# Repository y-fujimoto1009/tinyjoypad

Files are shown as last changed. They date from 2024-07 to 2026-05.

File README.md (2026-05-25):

# tinyjoypad キット

tinyjoypad キットは、attiny85を使ったゲーム機を作成するためのキットです。<br>
tinyjoypadプロジェクトは
[こちら](https://www.tinyjoypad.com/tinyjoypad_attiny85) 



## 内容物


- 基板 x 1
- LED x 1
- ピンヘッダー（2×3） x 1
- スライドスイッチ x 1
- attiny85 x 1
- 丸ピンICソケット (8P) x 1
- 抵抗（10kΩ） x 2
- 抵抗（22kΩ） x 2
- 抵抗（33kΩ） x 2
- 抵抗（91kΩ） x 2
- タクトスイッチ x 5
- スイッチキャップ x 5
- ブザー x 1
- ボタン電池ホルダー x 1
- 0.96インチ有機ELディスプレイ(OLED)  x 1
- USBasp AVRライタ x 1(スイッチサイエンスで購入した方のみ）

## 自分で用意する必要があるもの
最近は100均などでも手に入りますね。
- はんだごて、はんだ
- マスキングテープ
- ニッパー
- ボタン電池（CR2032）

## 作成手順
1. 抵抗を基板に書かれた場所に配置します。間違えないようにしましょう。向きは関係ありません。<br>
はんだで接続できたら、余った足はニッパーでカットしてOKです。
どの抵抗かわからなくなっても落ち着いてカラーコードを確認すれば大丈夫です。<br>

<br>
 10kΩ：茶赤黒黒茶<br><br>
 
 22kΩ：赤赤黒赤茶<br><br>
 
 33kΩ：橙橙黒赤茶<br><br>
 
 91kΩ：茶赤黒茶白<br>

 

2. OLEDを取り付けます。斜めにならないようにマスキングテープなどで固定してからはんだ付けしましょう。<br><br>


3. 電源スイッチを下に向けて取り付けます。ぐらぐらしますので、マスキングテープなどで仮固定してからはんだ付けしましょう。<br><br>


4. タクトスイッチを取り付けます。向きは関係ありません。スイッチキャップも付けましょう。あまり強く押さなくても取り付けられます。<br><br>


5. LEDを取り付けます。足の短い方（カノード）をGNDの方にして取り付けてください。余った足はニッパーでカットしてOKです。<br><br>
IMG_1461 (1)

6. ピンヘッダ、ICソケットを取り付けます。ICソケットにはattiny85を取り付けます。attiny85は左側にくぼみがくるように取り付けてください。<br><br>
IMG_1463 (1)

7. ブザーも向きがあります。＋と書いてる方を間違えずに取り付けてください。これで表面は完成です。<br><br>
IMG_1464 (3)

8. 裏を向けてボタン電池ホルダーを取り付けます。今までと違い表面実装部品なので、先に基板にはんだを少し盛ってから、上から温めて接続するとうまくいきます。<br><br>



あとは電池を＋面が表になるように接続して電源をONにすればゲームが起動するはずです！おめでとう！
起動しない場合ははんだのミス（隣と接続されてしまっている箇所が無いかなど）、attiny85の向き、取付忘れなどないか確認してください。
お問い合わせはk.u.i.f1009@gmail.comまで

## プログラムのインストール手順
初期状態でスペースインベーダーをインストールしていますが、tinyjoypadプロジェクトでは他にも面白いゲームが公開されています。
現状(2024年7月時点）でうまくいったインストール手順を紹介します。

1. [Zadig](https://zadig.akeo.ie/)にアクセスして、Zadigソフトをインストールします。
2. キットについているUSBaspをPCと接続します。
3. Zadigを起動し、USBaspを選択してlibusbkを選択してインストールします。
4. [ArduinoIDE](https://www.arduino.cc/en/software)をインストールします。
5. 基本設定ー＞追加のボードマネージャのURLに次のURLを追加します。https://descartes.net/package_drazzy.com_index.json
6. ツールー＞ボードー＞ボードマネージャの検索欄にattinyと入力してATTinyCore by Spence Kondeのバージョン1.3.2を選択してインストールします。
8. [SSD1306ライブラリ](https://github.com/Defragster/ssd1306xled)をダウンロードし、スケッチー＞ライブラリをインクルードー＞.ZIP形式のライブラリをインストールへと進み、ダウンロードしたzipファイルを選択してインストールを行います。
9. [ゲームデータ](https://github.com/cheungbx/gametiny)をダウンロード、解凍し、好きなゲームの.inoファイルを起動します。
10. ツールー＞ボードー＞ATTinyCoreー＞Attiny25/45/85を選択します。
11. チップはATtiny85、クロックは8MHz(internal)、そして書込装置はUSBaspを選択します。
12. スケッチー＞書き込み装置を使って書き込むを選択します。
13. プログラムが書き込まれます。

詳細な手順やサンプルコードについては、[tinyjoypad](https://www.tinyjoypad.com/tinyjoypad_attiny85)も参照してください。

## 自分で基板を発注してみる
gbrフォルダにあるファイルをJLCPCBなどの基板発注サービスなどに依頼すれば自分で発注することができます。
また、基板データを改造・修正する場合のライセンスはGPLv3です。

## 3Dプリンターでケースを作る
3dmodelフォルダにあるファイルをそのまま3Dプリンターなどで印刷すればケースを付けることができます。M2×15のビスが4本必要です。



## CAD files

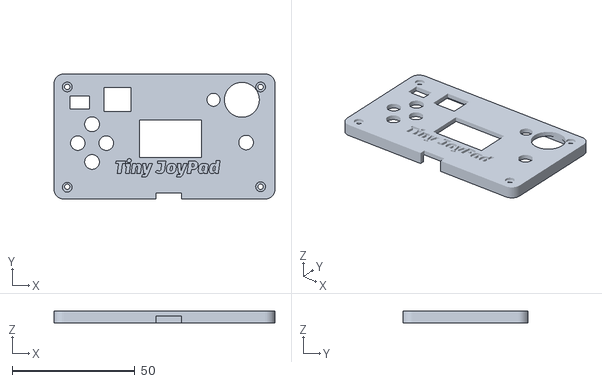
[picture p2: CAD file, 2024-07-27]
3dmodel/ボディ2.stl
90.0 x 51.0 x 5.00

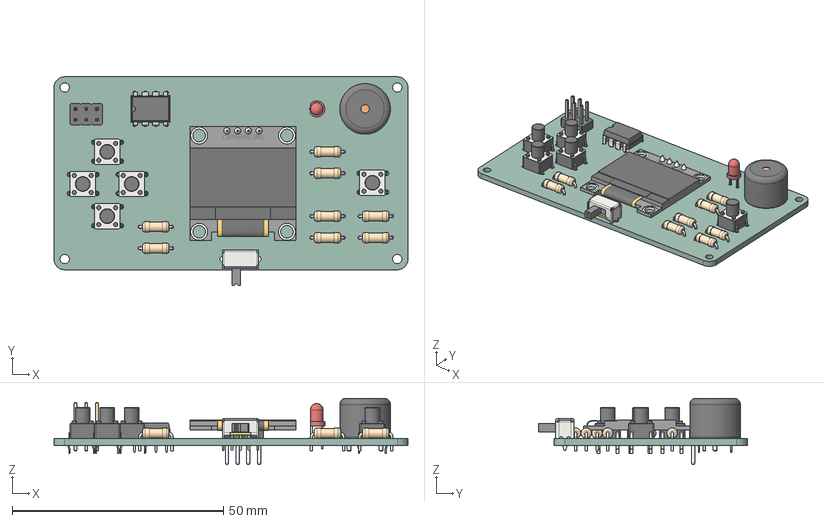
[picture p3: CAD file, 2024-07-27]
kicad/gamepad_attiny85.step
83.8 x 49.4 x 15.7 mm
R_Axial_DIN0207_L63mm_D25mm_P762mm_Horizontal x 8
SW_PUSH_6mm_h7.3mm x 5
LED_D3.0mm
DIP-8_W7.62mm
Buzzer_12x95RM76
SSD1306 v23
PinHeader_2x03_P254mm_Vertical
SW_Slide_SPDT_Angled_CK_OS102011MA1Q
gamepad_attiny85_PCB

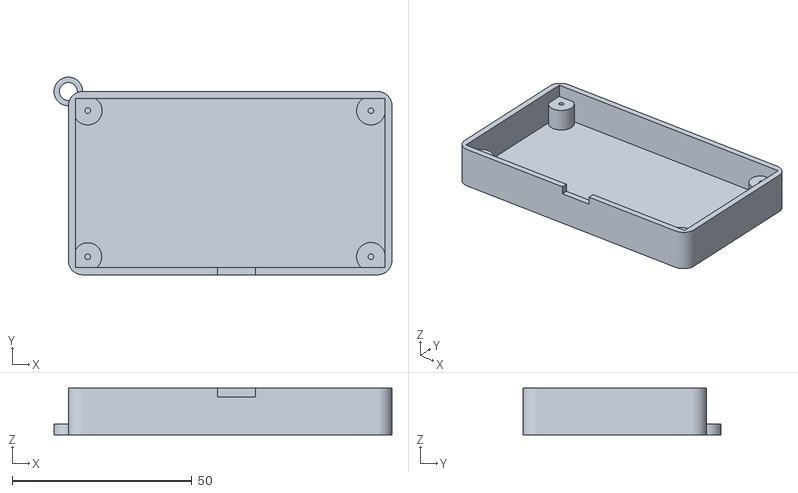
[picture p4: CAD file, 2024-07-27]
3dmodel/ボディ1.stl
94.0 x 55.0 x 13.0

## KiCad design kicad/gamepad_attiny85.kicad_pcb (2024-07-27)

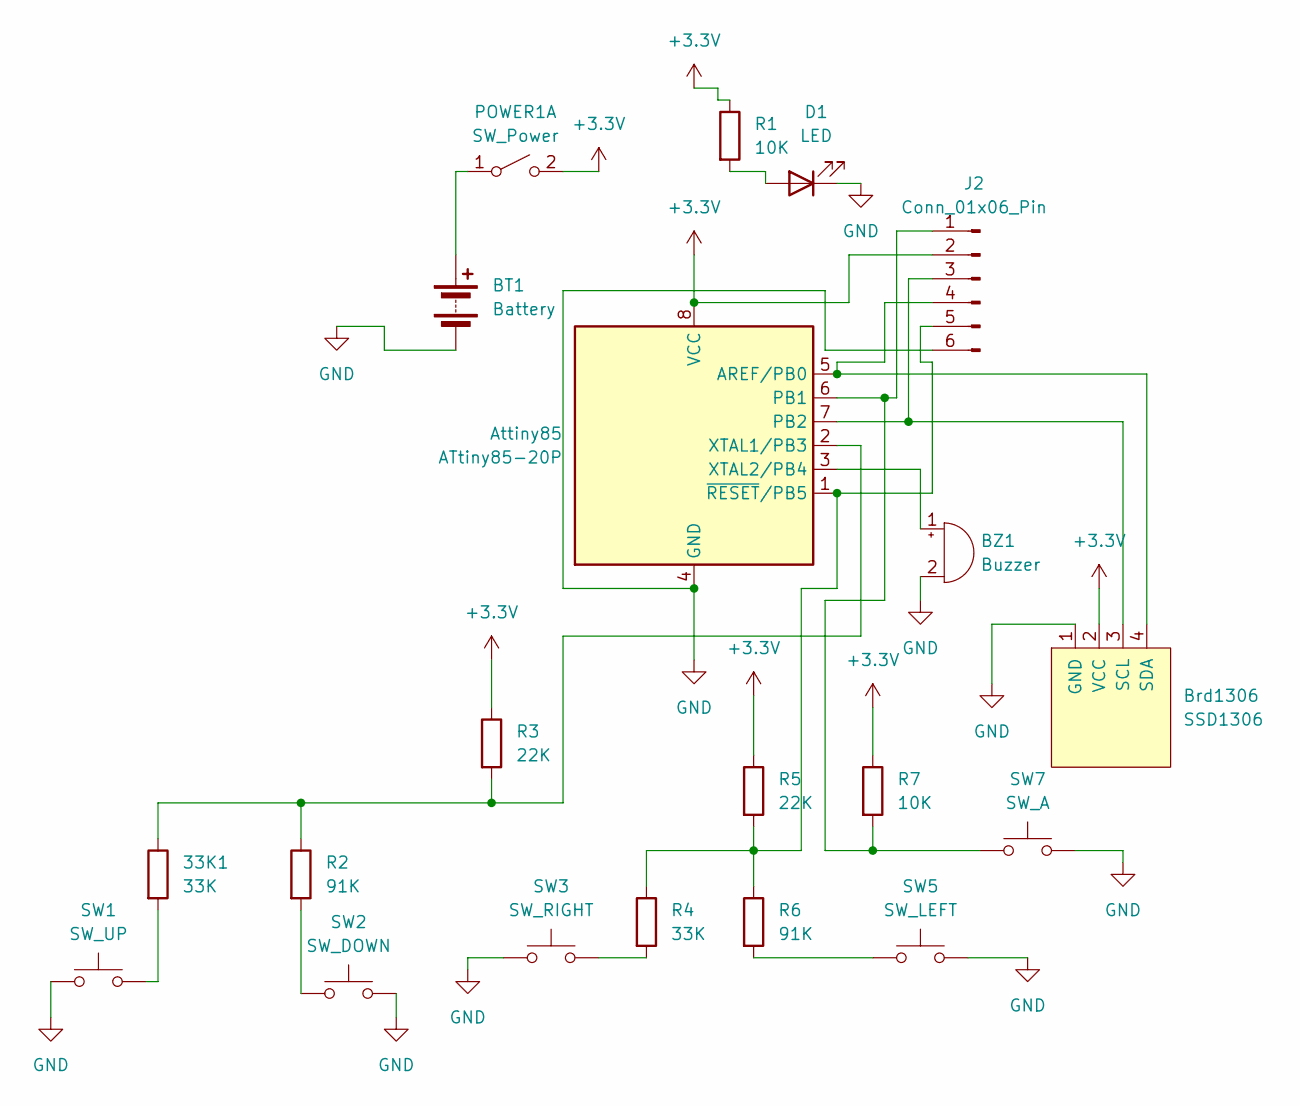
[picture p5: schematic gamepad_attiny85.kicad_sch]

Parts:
33K1: 33K; R_Axial_DIN0207_L6.3mm_D2.5mm_P7.62mm_Horizontal
Attiny85: ATtiny85-20P; DIP-8_W7.62mm
BT1: Battery; BatteryHolder_Renata_SMTU2032-LF_1x2032
BZ1: Buzzer; Buzzer_12x9.5RM7.6
Brd1306: SSD1306; 128x64OLED
D1: LED; LED_D3.0mm
J2: Conn_01x06_Pin; PinHeader_2x03_P2.54mm_Vertical
POWER1: SW_Power; SW_Slide_SPDT_Angled_CK_OS102011MA1Q
R1, R7: 10K; R_Axial_DIN0207_L6.3mm_D2.5mm_P7.62mm_Horizontal
R2, R6: 91K; R_Axial_DIN0207_L6.3mm_D2.5mm_P7.62mm_Horizontal
R3, R5: 22K; R_Axial_DIN0207_L6.3mm_D2.5mm_P7.62mm_Horizontal
R4: 33K; R_Axial_DIN0207_L6.3mm_D2.5mm_P7.62mm_Horizontal
SW1: SW_UP; SW_PUSH_6mm_H7.3mm
SW2: SW_DOWN; SW_PUSH_6mm_H7.3mm
SW3: SW_RIGHT; SW_PUSH_6mm_H7.3mm
SW5: SW_LEFT; SW_PUSH_6mm_H7.3mm
SW7: SW_A; SW_PUSH_6mm_H7.3mm

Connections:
+3.3V: Attiny85.8 (VCC), Brd1306.2 (VCC), J2.2, POWER1.2 (B), R1.1, R3.1, R5.1, R7.1
GND: Attiny85.4 (GND), BT1.2 (-), BZ1.2 (+), Brd1306.1 (GND), D1.1 (K), J2.6, SW1.1, SW2.2, SW3.1, SW5.2, SW7.2
unnamed: 33K1.2, SW1.2
unnamed: Attiny85.5 (AREF/PB0), Brd1306.4 (SDA), J2.4
unnamed: Attiny85.6 (PB1), J2.1, R7.2, SW7.1
unnamed: Attiny85.7 (PB2), Brd1306.3 (SCL), J2.3
unnamed: 33K1.1, Attiny85.2 (XTAL1/PB3), R2.1, R3.2
unnamed: Attiny85.3 (XTAL2/PB4), BZ1.1 (-)
unnamed: Attiny85.1 (~RESET/PB5), J2.5, R4.1, R5.2, R6.1
unnamed: BT1.1 (+), POWER1.1 (A)
unnamed: D1.2 (A), R1.2
unnamed: R2.2, SW2.1
unnamed: R4.2, SW3.2
unnamed: R6.2, SW5.1

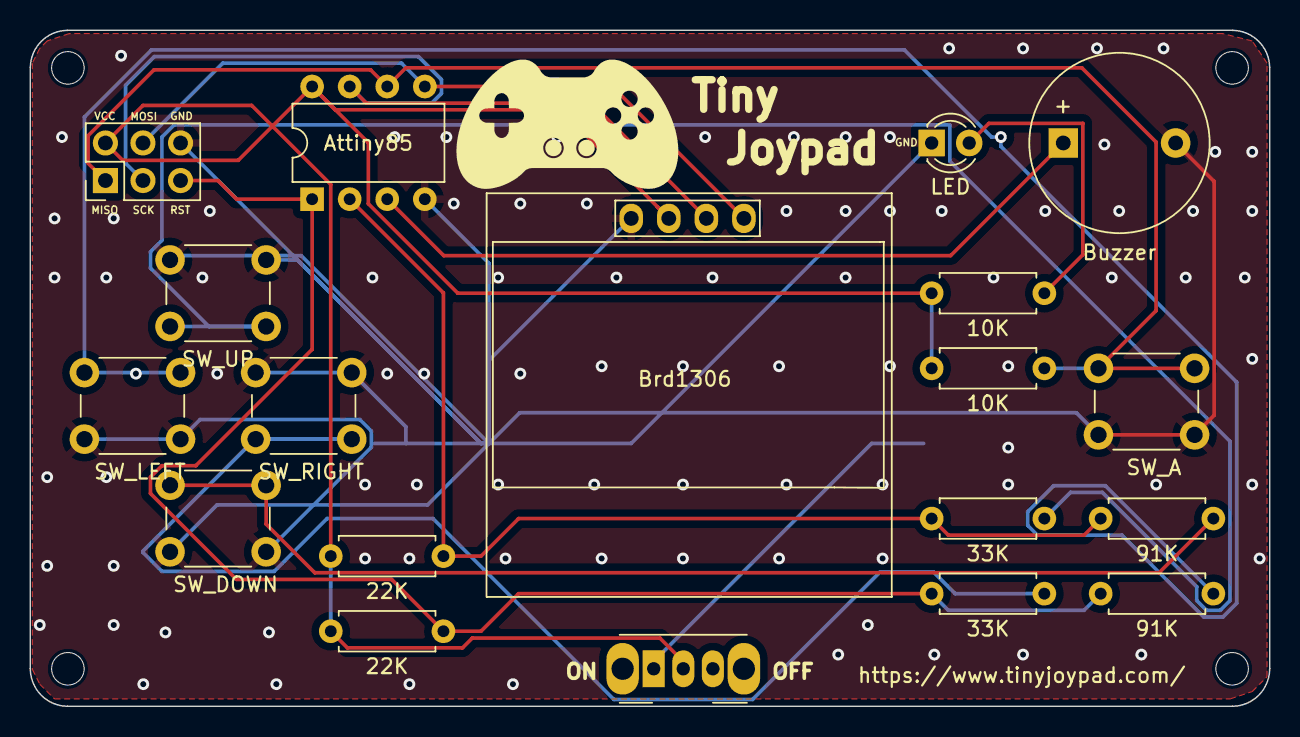
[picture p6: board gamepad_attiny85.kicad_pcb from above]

Board: 2 copper layers, 83.8 x 45.7 mm, 20 parts (1 on the bottom side), 14 nets.
